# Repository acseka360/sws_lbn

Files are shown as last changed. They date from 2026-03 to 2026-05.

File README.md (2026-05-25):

# Lora Battery Node
## Solder WorkShop - *Advanced Track*

### PCB

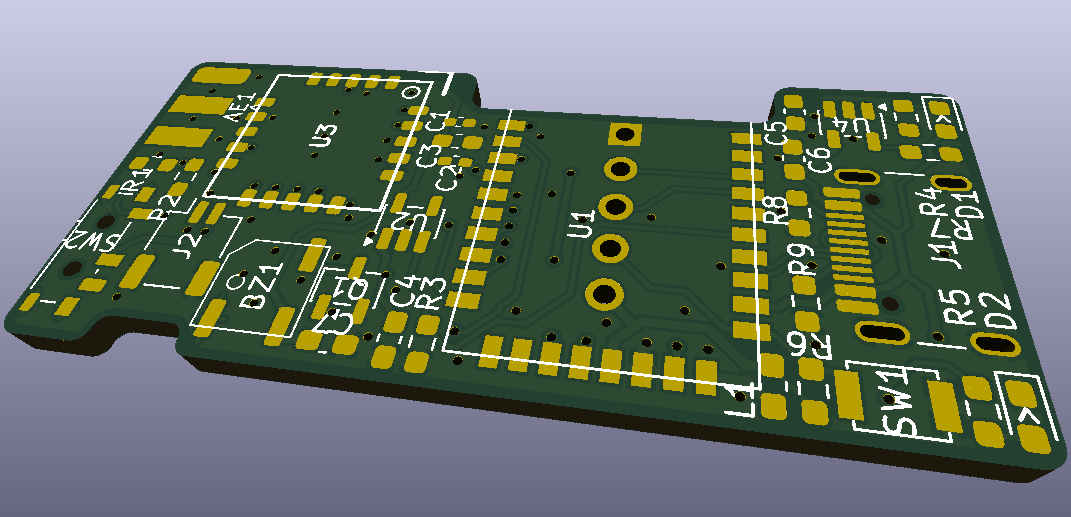
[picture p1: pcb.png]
PCB


Check out the PCB files with [Kicad 10](https://www.kicad.org/)

- Open the kicad\_pro project file
- Look at the schematic with the "Schematic Editor"
- Proceed to the "PCB editor" and push Alt-F3 to get into the 3D viewer

### Assembly

The interactive [BOM
webpage](https://htmlpreview.github.io/?https://github.com/acseka360/sws_lbn/blob/master/bom/ibom.html)
helps during assembly. You can mark components placed and check their exact
types.

### Bootloader

Initially a [J-Link](https://www.segger.com/products/debug-probes/j-link/) or
equivalent swd flasher is needed to load the bootloader on the virgin chip.

Use the *pca10056* type from the
[Adafruit](https://github.com/adafruit/Adafruit_nRF52_Bootloader/releases) repo.

### Firmware

You will need [PlatformIO](https://platformio.org/) to compile and install it.

First the bootstrapping firmware is needed, to set the IO voltages to 3.3V
permanently from the default 1.8V.

Then you can get the upstream
[Meshtastic](https://github.com/meshtastic/firmware) repo, that you should merge 
into the firmware folder, where our custom variant files already describe the 
board.

### 3D printed case

[Freecad 1.1](https://www.freecad.org/) made the 3d printed case files.

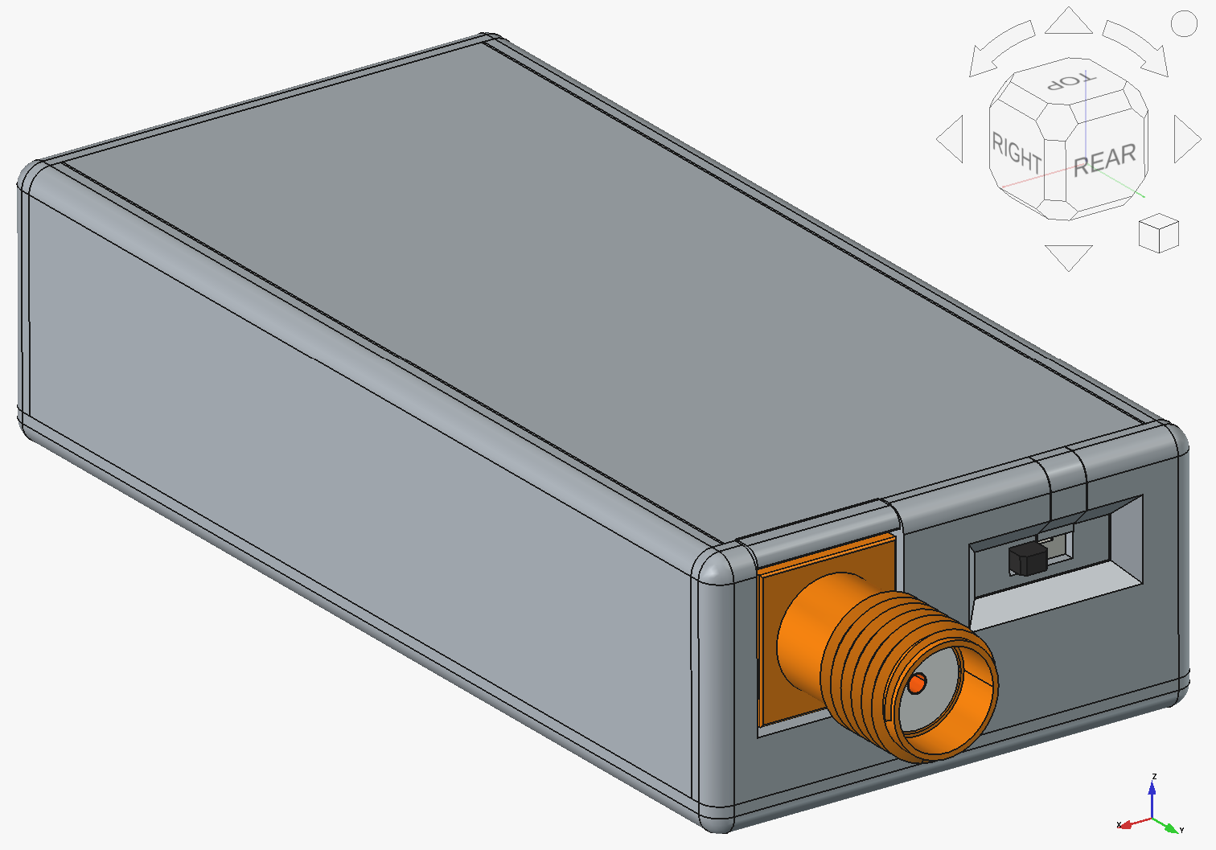
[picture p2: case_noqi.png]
case


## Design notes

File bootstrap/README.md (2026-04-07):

# E73 REGOUT0 3.3V Provisioner

Minimal PlatformIO project for your E73/nRF52840 board.

## What it does
- Brings up USB CDC serial at 115200
- Enables both nRF52840 DC/DC stages at runtime
- Prints current POWER/UICR state
- Programs `UICR->REGOUT0` to 3.3V
- Reads it back and keeps blinking `P0.05`

## Important
This changes UICR persistently. After flashing and seeing `setRegout0To3V3() = OK`, power-cycle the board and re-measure `VDD`.

## Build
```bash
pio run -v
```

## Serial
Open `/dev/ttyACM0` at 115200.

## After programming
1. Unplug power
2. Power the board again
3. Measure E73 `VDD`
4. Retry the radio firmware once `VDD` is near 3.3V

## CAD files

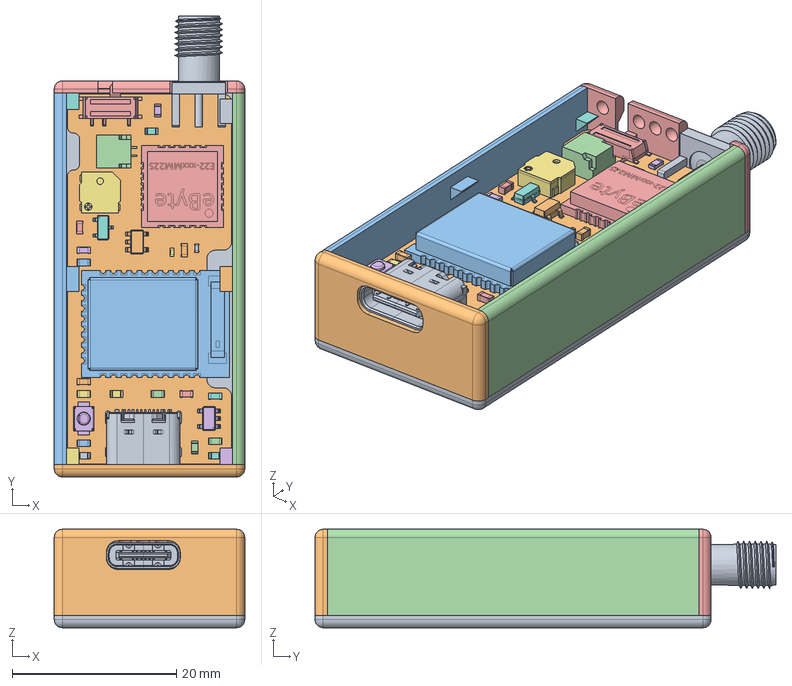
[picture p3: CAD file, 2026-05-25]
case/lbn_v2.FCStd
23.2 x 56.1 x 12.0 mm
JST_SH_SM02B-SRSS-TB_1x02-1MP_P1.00mm_Horizontal001
Fusion_sp
SW_SPST_B3U-1000P001
123FE607-BFB8-4806-9C67-8C4365AC7EAE
C_0603_1608Metric006
LED_0603_1608Metric003
SOT-23-002
R_0603_1608Metric010
R_0603_1608Metric012
C_0603_1608Metric008
R_0603_1608Metric014
R_0603_1608Metric016
R_0603_1608Metric018
USB_C_Receptacle_16P_TopMnt_Horizontal_GCT_USB4105-xx-A
C_0603_1608Metric010
R_0603_1608Metric020
R_0603_1608Metric022
Lora E22-900MM22S001
SOT-23-004
R_0603_1608Metric024
SOT-23-3
SMA-50KE001
L_0603_1608Metric001
E73-2G4M08S1C001
R_0603_1608Metric026
C_0603_1608Metric012
C_0603_1608Metric014
C_0402_1005Metric
LED_0603_1608Metric005
C_0402_1005Metric002
lora_board_PCB001

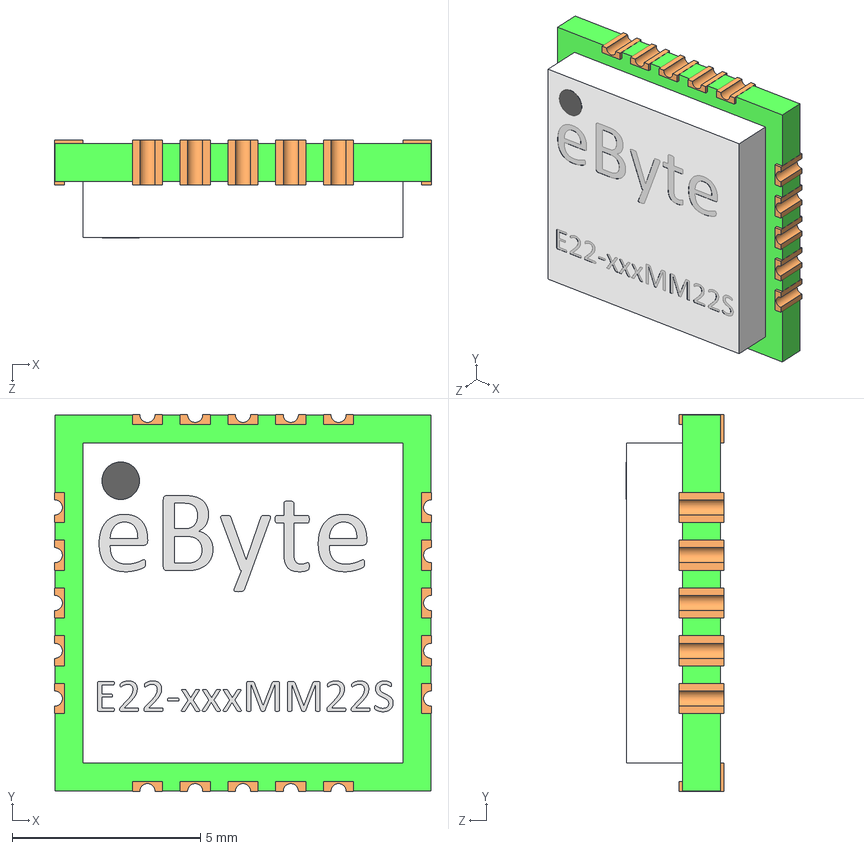
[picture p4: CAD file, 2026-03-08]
pcb/Lora E22-900MM22S.STEP
10.0 x 10.0 x 2.61 mm

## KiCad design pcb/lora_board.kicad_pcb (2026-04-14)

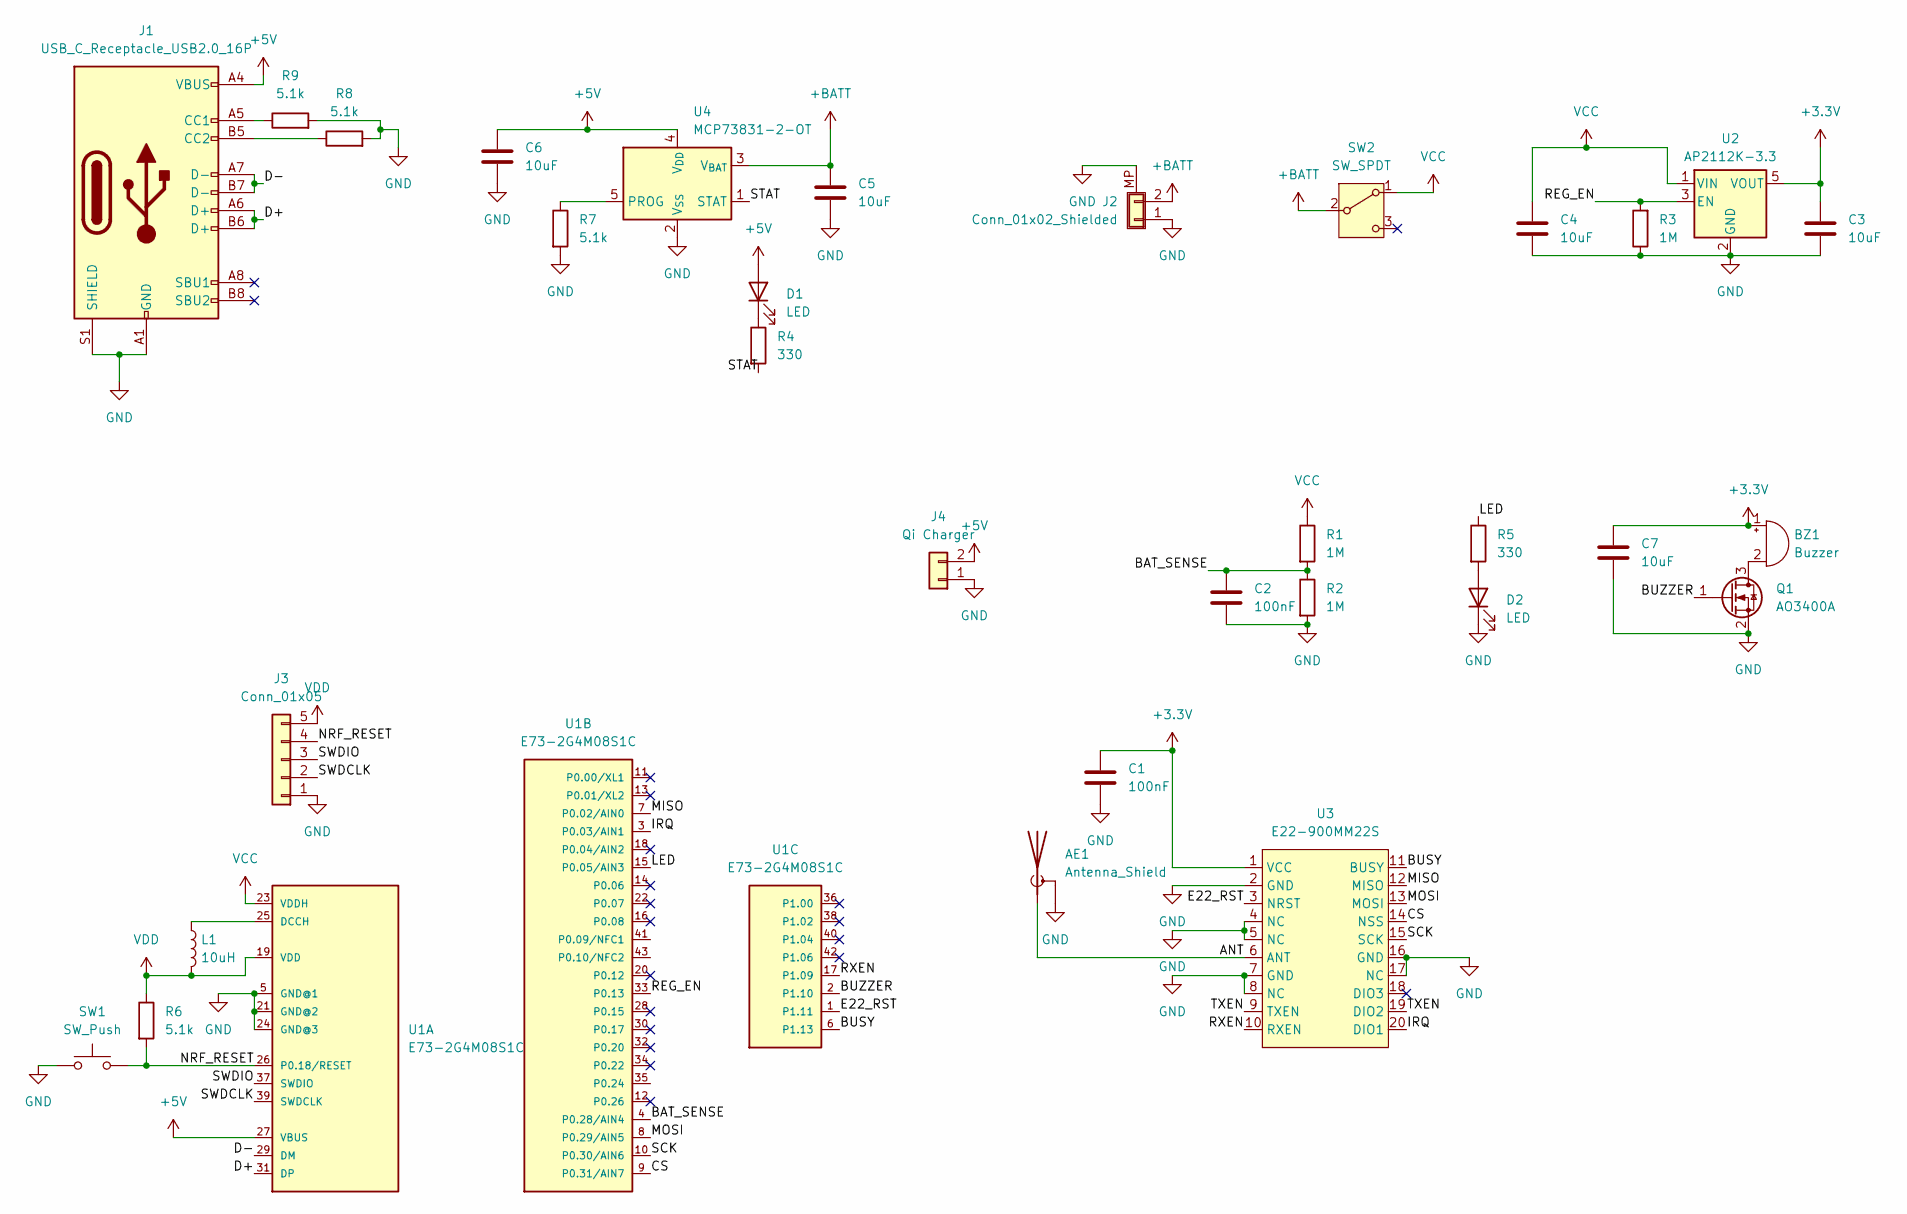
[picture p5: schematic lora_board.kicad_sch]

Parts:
AE1: Antenna_Shield; SMA_Amphenol_132289_EdgeMount
BZ1: Buzzer; MLT-5020
C1, C2: 100nF; C_0402_1005Metric_Pad0.74x0.62mm_HandSolder
C3, C4, C5, C6, C7: 10uF; C_0603_1608Metric_Pad1.08x0.95mm_HandSolder
D1, D2: LED; LED_0603_1608Metric_Pad1.05x0.95mm_HandSolder
J1: USB_C_Receptacle_USB2.0_16P; USB_C_Receptacle_GCT_USB4105-xx-A_16P_TopMnt_Horizontal
J2: Conn_01x02_Shielded; JST_SH_SM02B-SRSS-TB_1x02-1MP_P1.00mm_Horizontal
J3: Conn_01x05; PinHeader_1x05_P2.54mm_Vertical
J4: Qi Charger; QiCharger
L1: 10uH; L_0603_1608Metric_Pad1.05x0.95mm_HandSolder
Q1: AO3400A; SOT-23_Handsoldering
R1, R2, R3: 1M; R_0603_1608Metric_Pad0.98x0.95mm_HandSolder
R4, R5: 330; R_0603_1608Metric_Pad0.98x0.95mm_HandSolder
R6, R7, R8, R9: 5.1k; R_0603_1608Metric_Pad0.98x0.95mm_HandSolder
SW1: SW_Push; SW_SPST_B3U-1000P
SW2: SW_SPDT; SW_SPDT_PCM12
U1: E73-2G4M08S1C
U2: AP2112K-3.3; SOT-23-5_HandSoldering
U3: E22-900MM22S
U4: MCP73831-2-OT; SOT-23-5_HandSoldering

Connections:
+3.3V: BZ1.1 (+), C1.1, C3.1, C7.1, U2.5 (VOUT), U3.1 (VCC)
+5V: C6.1, D1.2 (A), J1.A4 (VBUS), J1.A9 (VBUS), J1.B4 (VBUS), J1.B9 (VBUS), J4.2, U1.27 (VBUS), U4.4 (V_{DD})
+BATT: C5.1, J2.2, SW2.2 (B), U4.3 (V_{BAT})
/ANT: AE1.1 (A), U3.6 (ANT)
/BAT_SENSE: C2.1, R1.2, R2.1, U1.4 (P0.28/AIN4)
/BUSY: U1.6 (P1.13), U3.11 (BUSY)
/BUZZER: Q1.1 (G), U1.2 (P1.10)
/CS: U1.9 (P0.31/AIN7), U3.14 (NSS)
/D+: J1.A6 (D+), J1.B6 (D+), U1.31 (DP)
/D-: J1.A7 (D-), J1.B7 (D-), U1.29 (DM)
/E22_RST: U1.1 (P1.11), U3.3 (NRST)
/IRQ: U1.3 (P0.03/AIN1), U3.20 (DIO1)
/LED: R5.1, U1.15 (P0.05/AIN3)
/MISO: U1.7 (P0.02/AIN0), U3.12 (MISO)
/MOSI: U1.8 (P0.29/AIN5), U3.13 (MOSI)
/NRF_RESET: J3.4, R6.2, SW1.2, U1.26 (P0.18/RESET)
/REG_EN: R3.2, U1.33 (P0.13), U2.3 (EN)
/RXEN: U1.17 (P1.09), U3.10 (RXEN)
/SCK: U1.10 (P0.30/AIN6), U3.15 (SCK)
/STAT: R4.2, U4.1 (STAT)
/SWDCLK: J3.2, U1.39 (SWDCLK)
/SWDIO: J3.3, U1.37 (SWDIO)
/TXEN: U3.9 (TXEN), U3.19 (DIO2)
GND: AE1.2 (Shield), C1.2, C2.2, C3.2, C4.2, C5.2, C6.2, C7.2, D2.1 (K), J1.A1 (GND), J1.A12 (GND), J1.B1 (GND), J1.B12 (GND), J1.S1 (SHIELD), J2.1, J2.MP (Shield), J3.1, J4.1, Q1.2 (S), R2.2, R3.1, R7.2, R8.2, R9.2, SW1.1, U1.5 (GND@1), U1.21 (GND@2), U1.24 (GND@3), U2.2 (GND), U3.2 (GND), U3.4 (NC), U3.5 (NC), U3.7 (GND), U3.8 (NC), U3.16 (GND), U3.17 (NC), U4.2 (V_{SS})
unnamed: BZ1.2 (-), Q1.3 (D)
unnamed: D1.1 (K), R4.1
unnamed: D2.2 (A), R5.2
unnamed: J1.A5 (CC1), R9.1
unnamed: J1.B5 (CC2), R8.1
unnamed: L1.1, U1.25 (DCCH)
unnamed: R7.1, U4.5 (PROG)
VCC: C4.1, R1.1, SW2.1 (A), U1.23 (VDDH), U2.1 (VIN)
VDD: J3.5, L1.2, R6.1, U1.19 (VDD)

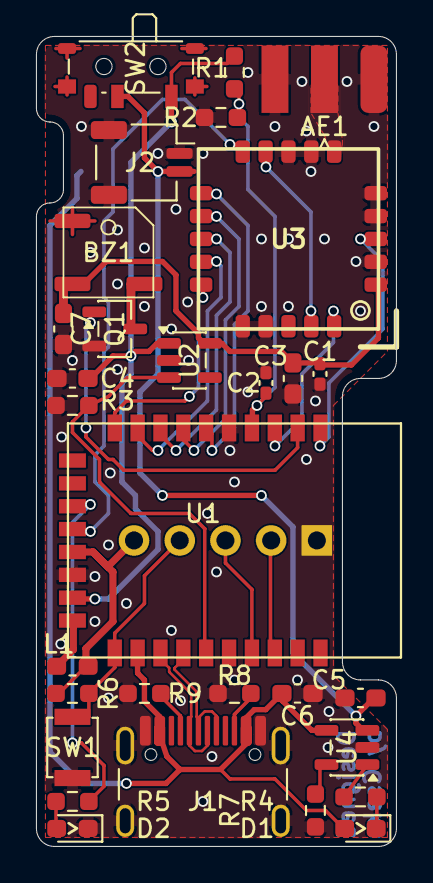
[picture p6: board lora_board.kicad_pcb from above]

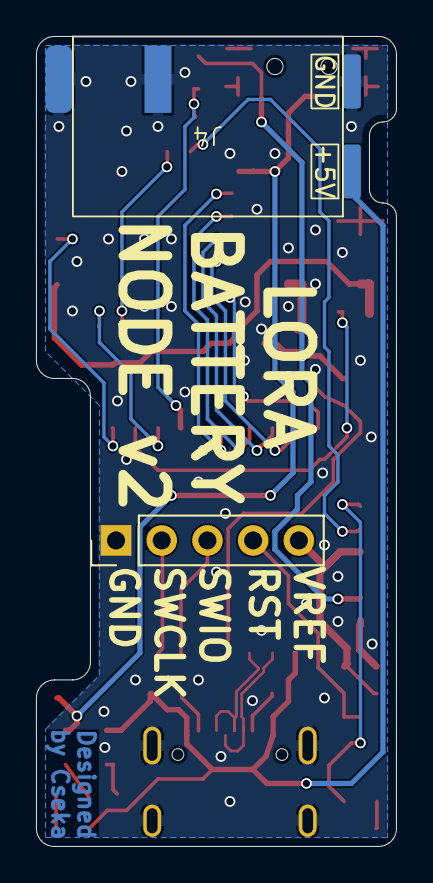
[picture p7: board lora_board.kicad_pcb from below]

Board: 2 copper layers, 20.0 x 45.0 mm, 32 parts (2 on the bottom side), 33 nets.

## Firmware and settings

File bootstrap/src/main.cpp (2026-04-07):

#include <Arduino.h>
#include "Adafruit_TinyUSB.h"
#include "nrf.h"

static constexpr uint8_t LED_PIN = PIN_LED1;
static constexpr bool LED_ACTIVE_HIGH = true;

static void setLed(bool on) {
  digitalWrite(LED_PIN, (on == LED_ACTIVE_HIGH) ? HIGH : LOW);
}

static void waitForNvmc() {
  while (NRF_NVMC->READY == NVMC_READY_READY_Busy) {
  }
}

static const char *regout0_to_str(uint32_t v) {
  switch (v & UICR_REGOUT0_VOUT_Msk) {
    case (UICR_REGOUT0_VOUT_DEFAULT << UICR_REGOUT0_VOUT_Pos): return "DEFAULT";
#ifdef UICR_REGOUT0_VOUT_1V8
    case (UICR_REGOUT0_VOUT_1V8 << UICR_REGOUT0_VOUT_Pos): return "1.8V";
#endif
#ifdef UICR_REGOUT0_VOUT_2V1
    case (UICR_REGOUT0_VOUT_2V1 << UICR_REGOUT0_VOUT_Pos): return "2.1V";
#endif
#ifdef UICR_REGOUT0_VOUT_2V4
    case (UICR_REGOUT0_VOUT_2V4 << UICR_REGOUT0_VOUT_Pos): return "2.4V";
#endif
#ifdef UICR_REGOUT0_VOUT_2V7
    case (UICR_REGOUT0_VOUT_2V7 << UICR_REGOUT0_VOUT_Pos): return "2.7V";
#endif
#ifdef UICR_REGOUT0_VOUT_3V0
    case (UICR_REGOUT0_VOUT_3V0 << UICR_REGOUT0_VOUT_Pos): return "3.0V";
#endif
#ifdef UICR_REGOUT0_VOUT_3V3
    case (UICR_REGOUT0_VOUT_3V3 << UICR_REGOUT0_VOUT_Pos): return "3.3V";
#endif
    default: return "UNKNOWN";
  }
}

static void dumpPowerState() {
  uint32_t dcdcen  = NRF_POWER->DCDCEN;
  uint32_t dcdcen0 = NRF_POWER->DCDCEN0;
  uint32_t mainreg = NRF_POWER->MAINREGSTATUS;
  uint32_t regout0 = NRF_UICR->REGOUT0;

  Serial.println("=== POWER STATE ===");
  Serial.print("NRF_POWER->DCDCEN         = 0x"); Serial.println(dcdcen, HEX);
  Serial.print("NRF_POWER->DCDCEN0        = 0x"); Serial.println(dcdcen0, HEX);
  Serial.print("NRF_POWER->MAINREGSTATUS  = 0x"); Serial.println(mainreg, HEX);
  Serial.print("NRF_UICR->REGOUT0         = 0x"); Serial.println(regout0, HEX);
  Serial.print("REGOUT0 decoded           = ");   Serial.println(regout0_to_str(regout0));
  Serial.println();
}

static bool setRegout0To3V3() {
#ifdef UICR_REGOUT0_VOUT_3V3
  const uint32_t wanted = (UICR_REGOUT0_VOUT_3V3 << UICR_REGOUT0_VOUT_Pos);
#else
  return false;
#endif

  if ((NRF_UICR->REGOUT0 & UICR_REGOUT0_VOUT_Msk) == wanted) {
    return true;
  }

  NRF_NVMC->CONFIG = NVMC_CONFIG_WEN_Wen;
  waitForNvmc();

  NRF_UICR->REGOUT0 = (NRF_UICR->REGOUT0 & ~UICR_REGOUT0_VOUT_Msk) | wanted;
  waitForNvmc();

  NRF_NVMC->CONFIG = NVMC_CONFIG_WEN_Ren;
  waitForNvmc();

  return ((NRF_UICR->REGOUT0 & UICR_REGOUT0_VOUT_Msk) == wanted);
}

void setup() {
  pinMode(LED_PIN, OUTPUT);
  setLed(false);

  Serial.begin(115200);
  delay(1500);

  Serial.println();
  Serial.println("E73 REGOUT0 3.3V provisioner");
  Serial.println("This writes UICR->REGOUT0 once, then blinks forever.");
  Serial.println();

  NRF_POWER->DCDCEN  = 1;
  NRF_POWER->DCDCEN0 = 1;

  Serial.println("Before programming:");
  dumpPowerState();

  bool ok = setRegout0To3V3();

  Serial.print("setRegout0To3V3() = ");
  Serial.println(ok ? "OK" : "FAILED");
  Serial.println();

  Serial.println("After programming readback:");
  dumpPowerState();

  Serial.println("Now power-cycle the board and re-measure E73 VDD.");
  Serial.println("Expected result: VDD near 3.3V instead of ~1.8V.");
}

void loop() {
  static uint32_t last = 0;
  static bool led = false;

  uint32_t now = millis();
  if (now - last >= 500) {
    last = now;
    led = !led;
    setLed(led);
    Serial.print("uptime_ms=");
    Serial.println(now);
  dumpPowerState();
  }
}

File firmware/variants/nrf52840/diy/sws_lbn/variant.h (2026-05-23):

#ifndef _VARIANT_E73_E22_900MM22S_USB_
#define _VARIANT_E73_E22_900MM22S_USB_

#define VARIANT_MCK (64000000ul)

/* E73 module has no external 32.768 kHz crystal; use internal RC oscillator */
#define USE_LFRC

/* Board capabilities */
#define PRIVATE_HW
#define HAS_SCREEN            0
#define HAS_WIRE              0
#define HAS_GPS               0
#define HAS_SENSOR            0
#define HAS_PHYSICAL_KEYBOARD 0
#define HAS_CPU_SHUTDOWN      0

/* Exclude unused Meshtastic modules */
#define MESHTASTIC_EXCLUDE_I2C                   1
#define MESHTASTIC_EXCLUDE_ENVIRONMENTAL_SENSOR  1
#define MESHTASTIC_EXCLUDE_AIR_QUALITY_SENSOR    1
#define MESHTASTIC_EXCLUDE_DETECTIONSENSOR       1
#define MESHTASTIC_EXCLUDE_INPUTBROKER           1
#define MESHTASTIC_EXCLUDE_CANNEDMESSAGES        1
#define MESHTASTIC_EXCLUDE_GPS                   1
#define MESHTASTIC_EXCLUDE_SCREEN                1
#define MESHTASTIC_EXCLUDE_WAYPOINT              1

#include "WVariant.h"

#ifdef __cplusplus
extern "C" {
#endif

/*
 * E73-2G4M08S1C + E22-900MM22S pin assignment
 *
 * MCU pin   Function
 * -------   --------------------------------------------------------
 * P0.02     SPI MISO
 * P0.03     SX1262 DIO1 / IRQ
 * P0.05     LED (active-high)
 * P0.13     3.3V rail enable for E22 and buzzer (shared supply)
 * P0.28     Battery voltage sense, 1/2 resistor divider
 * P0.29     SPI MOSI
 * P0.30     SPI SCK
 * P0.31     SX1262 NSS / CS
 * P1.09     SX1262 RXEN
 * P1.10     Buzzer via N-channel MOSFET (active-high gate)
 * P1.11     SX1262 NRST
 * P1.13     SX1262 BUSY
 *
 * Notes:
 * - On the E22-900MM22S, DIO2 is wired internally to TXEN, so the
 *   radio handles TX switching autonomously via SX126X_DIO2_AS_RF_SWITCH.
 *   The MCU only needs to drive RXEN (P1.09).
 * - P0.13 powers both the E22 and the buzzer MOSFET drain supply.
 *   PIN_POWER_EN raises this rail early in boot so the buzzer is
 *   available before the radio driver initialises.
 * - No button, GPS, I2C, or display on this PCB.
 */

#define PINS_COUNT           (48)
#define NUM_DIGITAL_PINS     (48)
#define NUM_ANALOG_INPUTS    (1)
#define NUM_ANALOG_OUTPUTS   (0)

#define BATTERY_PIN    (0 + 28)
#define ADC_MULTIPLIER 2.0      /* 1/2 resistor divider on BATTERY_PIN */

#define PIN_LED1      (0 + 5)  /* P0.05 */
#define LED_STATE_ON  1

#define PIN_BUZZER    (32 + 10) /* P1.10 — N-channel MOSFET, active-high gate */
#define BUZZER_STATE  1

/* No UART pins routed on this PCB */
#define PIN_SERIAL1_RX  (-1)
#define PIN_SERIAL1_TX  (-1)
#define PIN_SERIAL2_RX  (-1)
#define PIN_SERIAL2_TX  (-1)

/* No I2C on this PCB. Count kept at 1 so third-party library headers that
   reference the global Wire object still compile under MESHTASTIC_EXCLUDE_I2C. */
#define WIRE_INTERFACES_COUNT 1
#define PIN_WIRE_SDA  (-1)
#define PIN_WIRE_SCL  (-1)

/* SPI — shared with SX1262 */
#define SPI_INTERFACES_COUNT 1
#define PIN_SPI_MISO  (0 + 2)   /* P0.02 */
#define PIN_SPI_MOSI  (0 + 29)  /* P0.29 */
#define PIN_SPI_SCK   (0 + 30)  /* P0.30 */

#define LORA_MISO  PIN_SPI_MISO
#define LORA_MOSI  PIN_SPI_MOSI
#define LORA_SCK   PIN_SPI_SCK
#define LORA_CS    (0 + 31)     /* P0.31 */
#define LORA_DIO1  (0 + 3)      /* P0.03 */
#define LORA_RESET (32 + 11)    /* P1.11 */
#define LORA_BUSY  (32 + 13)    /* P1.13 */

/* SX1262 radio */
#define USE_SX1262

#define SX126X_CS     LORA_CS
#define SX126X_DIO1   LORA_DIO1
#define SX126X_BUSY   LORA_BUSY
#define SX126X_RESET  LORA_RESET
#define SX126X_RXEN   (32 + 9)  /* P1.09 — driven by MCU */
#define SX126X_TXEN   RADIOLIB_NC /* TXEN handled internally by DIO2 on E22-900MM22S */
#define SX126X_DIO2_AS_RF_SWITCH  /* DIO2 wired to TXEN inside E22-900MM22S module */

/* P0.13 enables the 3.3V rail for the E22 and buzzer.
   PIN_POWER_EN causes main.cpp to raise this before any module init,
   ensuring the buzzer supply is live for the boot melody.
   SX126X_POWER_EN lets the radio driver gate it for power management. */
#define PIN_POWER_EN    (0 + 13)
#define SX126X_POWER_EN (0 + 13)

#ifdef __cplusplus
}
#endif

static const uint8_t SS   = LORA_CS;
static const uint8_t MOSI = PIN_SPI_MOSI;
static const uint8_t MISO = PIN_SPI_MISO;
static const uint8_t SCK  = PIN_SPI_SCK;

#endif /* _VARIANT_E73_E22_900MM22S_USB_ */

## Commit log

2026-02-12 ordered v1
    [E22-900M22S--3DModel-STEP-56544.STEP, HRMJ-U.FLJ-PC-1.stp, lora_board.kicad_pcb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]
2026-03-08 pre del
    [128x32-OLED.STEP, E22-900M30S--3DModel-STEP-418109.STEP, ESP32-S3-WROOM-1U--3DModel-STEP-56544.STEP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]
2026-03-14 pre del esp32-s3-supermini
    [lora_board.kicad_pcb, lora_board.kicad_sch]
2026-04-02 small ordered v1
    [lora_board.kicad_pcb, lora_board.kicad_sch]
2026-04-04 v2 rc1
    [lora_board.kicad_pcb, lora_board.kicad_sch]
2026-04-06 v2 rc2
    [lora_board.kicad_pcb, lora_board.kicad_sch]
2026-04-06 proper subfolders
    [128x32-OLED.STEP, E22-900M22S--3DModel-STEP-56544.STEP, E22-900M30S--3DModel-STEP-418109.STEP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]
2026-04-07 v2 rc3
    [lora_board.kicad_pcb, lora_board.kicad_sch]
2026-04-14 ordered v2
    [128x32-OLED.STEP, E22-900M22S--3DModel-STEP-56544.STEP, E22-900M30S--3DModel-STEP-418109.STEP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]
2026-05-25 case uploaded, and updated readme
    [lbn_v2.FCStd]
